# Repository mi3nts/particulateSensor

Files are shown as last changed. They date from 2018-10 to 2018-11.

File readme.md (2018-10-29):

# IoT Particulate Sensors

## Introduction 
With the increase in particulate emissions over the years, there is a need to be aware of the implications of toxic airbourne particles. These can have negative health outcomes on the population. Currently, air quality sensors are spaced far and wide from eachother collecting data at large time frames. They can also be often expensive. This project seeks to solve these issues and presents a low cost sensor network using a novel network communication known as LoRaWAN, a set of arduinos, and a gateway linux based Raspberry Pi 3. Combined with the calibration technique using machine learning algorithms, this sensor network can effectively provide the public with an accurate representation of air quality.

## Specifications
Uses a set of 10 arduino based nodes and 1 gateway Raspberry Pi 3.

- [Seeeduino LoRaWAN with GPS](https://m.seeedstudio.com/productDetail/2781/)
- [Grove Dust Sensor](https://www.seeedstudio.com/Grove-Dust-Sensor-p-1050.html/) 
- [Grove Barometer Sensor](https://www.seeedstudio.com/depot/Grove-Barometer-Sensor-BMP280-p-2652.html/) : I2C protocol

- Raspberry Pi 3 Model B
- [RHF0M301 module](http://www.risinghf.com/#/product-details?product_id=6&lang=en/) : serves as the communication bridge for the Raspberry Pi 3.

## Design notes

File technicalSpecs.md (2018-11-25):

# Low cost air quality IoT
This report gives the details of the sensor network and technical requirements.

## Primary Device: [Seeeduino LoRaWAN with GPS](https://m.seeedstudio.com/productDetail/2781/)
- Raspberry Pi 3 Model B
- [RHF0M301 module](http://www.risinghf.com/#/product-details?product_id=6&lang=en/)

### Sensors
These sensors are attached to the device.

| Sensor name | Description | Interface |
|---|---|---|
| [Grove Dust Sensor](https://www.seeedstudio.com/Grove-Dust-Sensor-p-1050.html/)  | Measures low pulse occupancy time as a correlate to particular matter. | Digital pin |
| [Grove Barometer Sensor](https://www.seeedstudio.com/depot/Grove-Barometer-Sensor-BMP280-p-2652.html/) | Measures temperature (celcius) and atmospheric pressure. | I2C | 
| [Grove Multichannel Gas Sensor](https://www.seeedstudio.com/Grove-Multichannel-Gas-Sensor-p-2502.html/) | Measures carbon monoxide, nitrogen dioxide, ethanol, hydrogen, ammonia, methane, propane, and isobutane in ppm. | I2C |

### Physical Characteristics
#### Dimensions
Seeeduino device dimensions with add-ons: 65mm x 55mm x 45mm (L x W x H) <br/>
Gateway device dimensions: 85mm x 55mm x 30mm (L x W x H, without antenna)

Seeeduino device enclosure: 120mm x 120mm x 275mm (L x W x H)
- See "3DModel" folder for computerized model of the casing.

Gateway device enclosure: X

#### Weight
Seeeduino device weight with add-ons: 0.25 kilograms <br/>
Gateway device weight: 0.20 kilograms

Seeeduino device with enclosure: 0.60 kilograms  </br>
Gateway device with enclosure: X

#### Power Requirements

Average power consumption on standby: 1.1 watt <br/>
Average power consumtpion during transmission: 1.2 watt <br/>
Voltage usage: 4.91 volts <br/>
Current usage: 0.20 amps

- [3.7 V Lithium Ion Battery](https://www.amazon.com/Battery-Lithium-2000mAh-Compatible-Controller/dp/B0137ITW46)
- [3W SEEED Solar Panel](https://cpc.farnell.com/seeed-studio/313070001/solar-panel-138x160-3w/dp/MK00376)

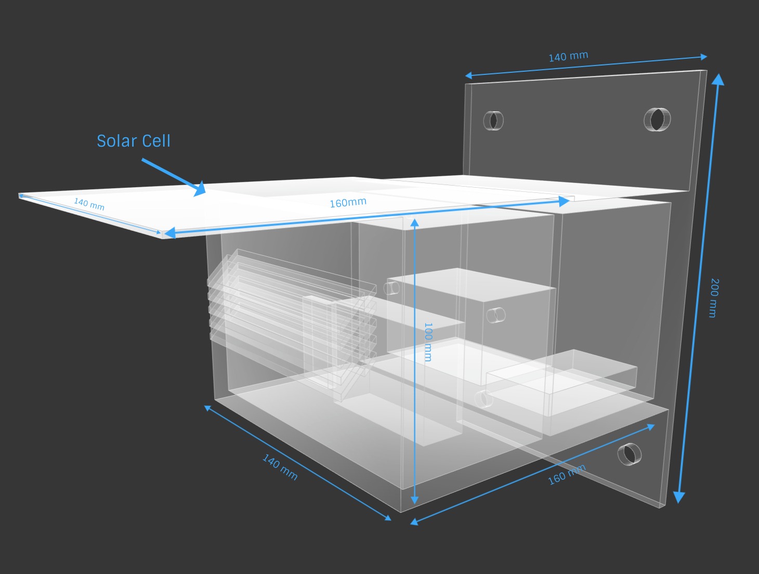
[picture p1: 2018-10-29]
3DModel/ParticulateSensor3.jpg

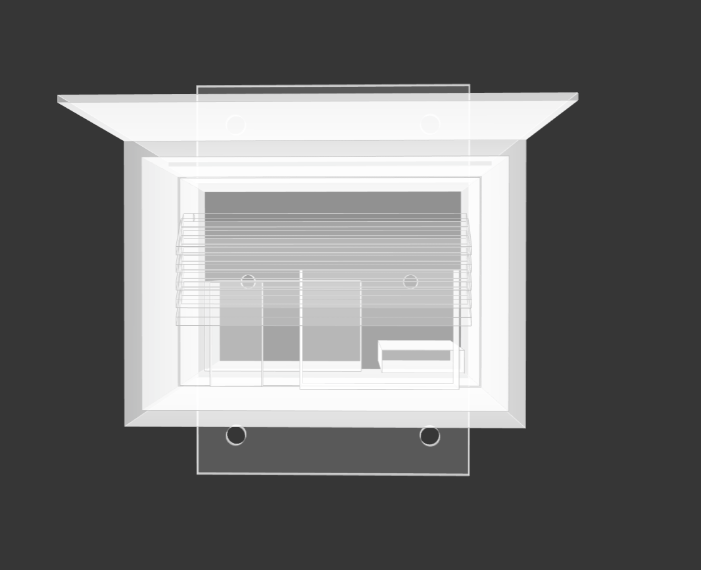
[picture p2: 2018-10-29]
3DModel/ParticulateSensor6.png

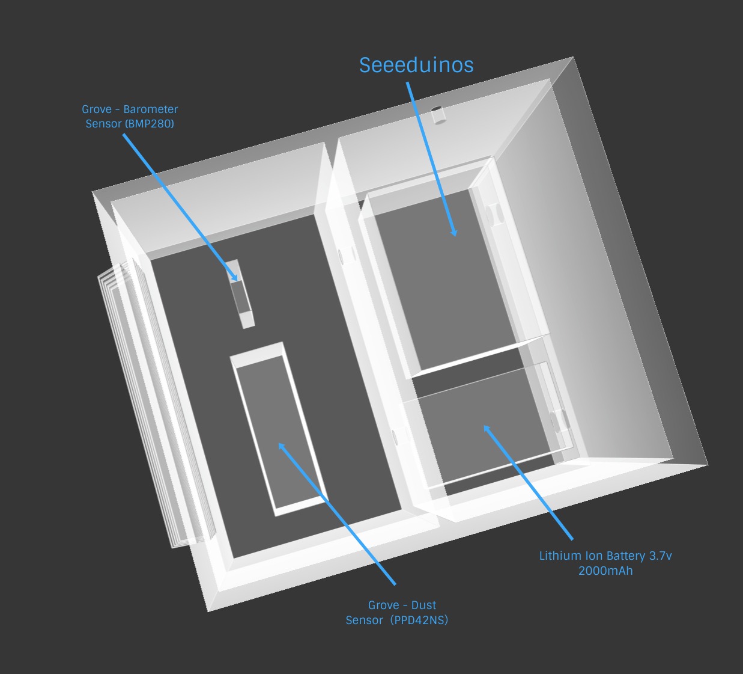
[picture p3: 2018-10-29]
3DModel/ParticulateSensor2.jpg

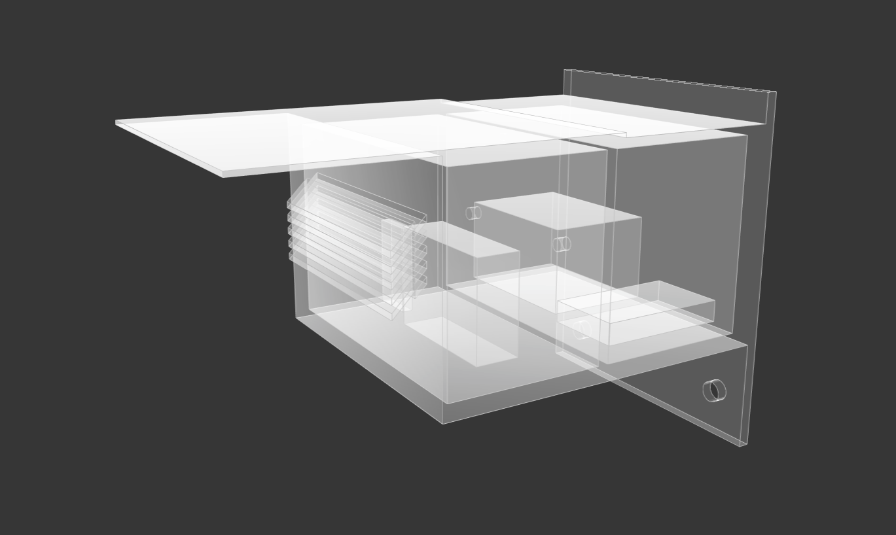
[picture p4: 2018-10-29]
3DModel/ParticulateSensor1.png

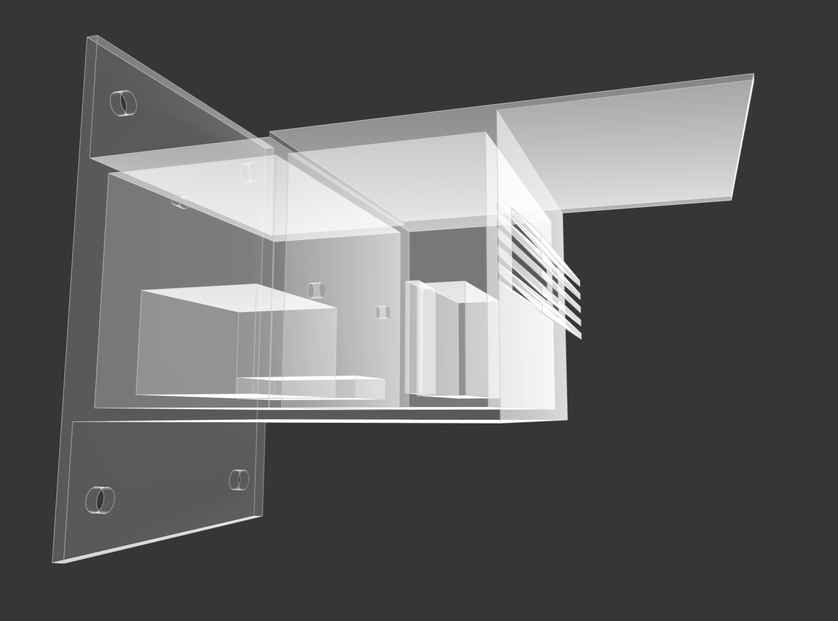
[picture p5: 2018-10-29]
3DModel/ParticulateSensor4.png

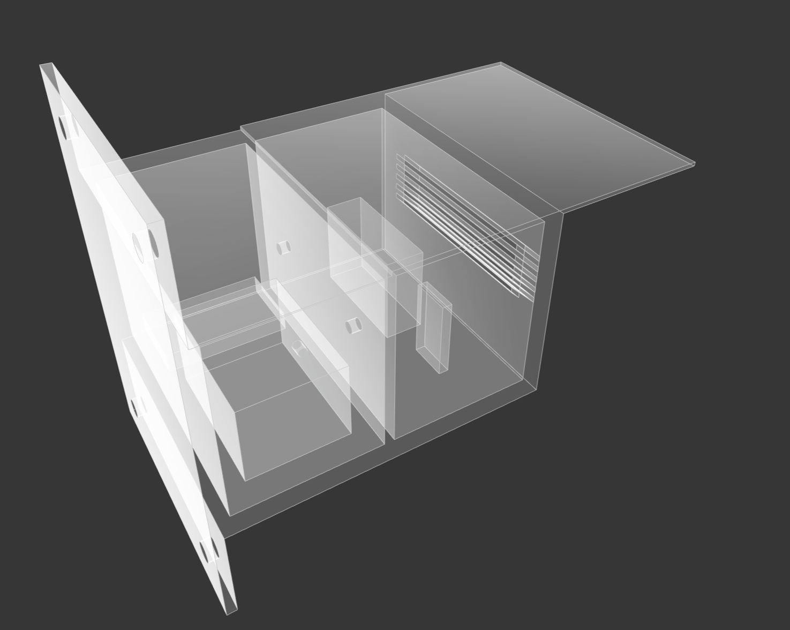
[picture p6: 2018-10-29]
3DModel/ParticulateSensor5.png

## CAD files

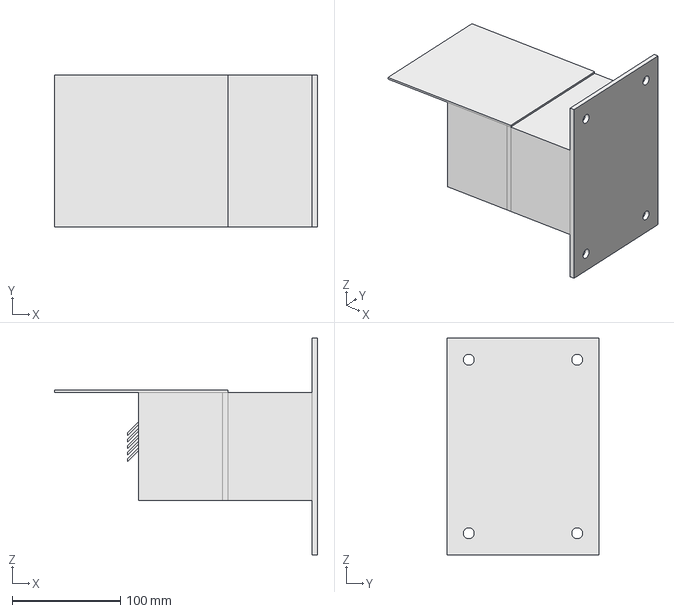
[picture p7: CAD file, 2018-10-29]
3DModel/ParticulateSensor.fcstd
242.5 x 140.0 x 200.0 mm

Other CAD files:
3DModel/ParticulateSensor.stl

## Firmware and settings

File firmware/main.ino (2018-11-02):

/*
 * MINTS
 * Written by Daniel Kiv
 * Version 0.1
 */

#include <math.h>
#include <stdio.h>
#include "Seeed_BMP280.h"
#include <Wire.h>
#include <LoRaWan.h>
#include "TinyGPS++.h"
#include <avr/dtostrf.h>
//#include "MutichannelGasSensor.h"

// gas sensors intializations
int pin = 8;
unsigned long duration;
unsigned long starttime;
unsigned long sampletime_ms = 1000;//sampe 30s ;
unsigned long lowpulseoccupancy = 0;
float ratio = 0;
float concentration = 0;

// bmp280 initializations
float pressure;
BMP280 bmp280;

#define USE_GPS 1
#ifdef USE_GPS
#include "TinyGPS++.h"
TinyGPSPlus gps;
#endif

const int analogInPin = A0;  // Analog input pin that the VBAT pin is attached to
int BatteryValue = 0;        // value read from the VBAT pin
float outputValue = 0;        // variable for voltage calculation

void setup() {

  char buffer[256];

  delay(1000);
  SerialUSB.println("Starting...");
  delay(1000);

   char c;
#ifdef USE_GPS
   bool locked;
#endif

  Serial.begin(9600);  // for gps readings
  Serial1.begin(9600);
  SerialUSB.begin(115200);
  lora.init();
  lora.setDeviceReset();

  #ifdef USE_GPS
    Serial.begin(9600);     // open the GPS
    locked = false;

    // For S&G, let's get the GPS fix now, before we start running arbitary
    // delays for the LoRa section

    while (!gps.location.isValid()) {
      while (Serial.available() > 0) {
        if (gps.encode(c=Serial.read())) {
//          displayInfo();
          if (gps.location.isValid()) {
//            locked = true;
            break;
          }
        }
//        SerialUSB.print(c);
      }

//      if (locked)
//        break;

      if (millis() > 15000 && gps.charsProcessed() < 10)
      {
        SerialUSB.println(F("No GPS detected: check wiring."));
        SerialUSB.println(gps.charsProcessed());
        while(true);
      }
      else if (millis() > 20000) {
        SerialUSB.println(F("Not able to get a fix in alloted time."));
        break;
      }
    }
#endif

  pinMode(pin,INPUT);
  if(!bmp280.init()) {
    SerialUSB.println("Device error!");
  }
  starttime = millis();//get the current time;

  // LoRaWan initializations
  memset(buffer, 0, 256);
  lora.getVersion(buffer, 256, 1);
  SerialUSB.print(buffer);

  memset(buffer, 0, 256);
  lora.getId(buffer, 256, 1);
  SerialUSB.print(buffer);

  lora.setKey("2B7E151628AED2A6ABF7158809CF4F3C", "2B7E151628AED2A6ABF7158809CF4F3C", NULL);

  lora.setDeciveMode(LWABP);
  lora.setDataRate(DR0, US915HYBRID);
//    sendCommand("AT+DR=US915HYBRID\r\n");

  lora.setChannel(0, 902.3);
  lora.setChannel(1, 902.5);
  lora.setChannel(2, 902.7);

//    lora.setChannel(0, 902.3, DR0, DR3);
//    lora.setChannel(1, 902.5, DR0, DR3);
//    lora.setChannel(2, 902.7, DR0, DR3);
//    lora.setChannel(3, 902.9, DR0, DR3);
//    lora.setChannel(4, 903.1, DR0, DR3);
//    lora.setChannel(5, 903.3, DR0, DR3);
//    lora.setChannel(6, 903.5, DR0, DR3);
//    lora.setChannel(7, 903.7, DR0, DR3);

//    lora.setReceiceWindowFirst(false);
//    lora.setReceiceWindowFirst(0, 923.3);
//    lora.setReceiceWindowFirst(1, 923.9);
//    lora.setReceiceWindowFirst(2, 924.5);
//    lora.setReceiceWindowFirst(3, 925.1);
//    lora.setReceiceWindowFirst(4, 925.7);
//    lora.setReceiceWindowFirst(5, 926.3);
//    lora.setReceiceWindowFirst(6, 926.9);
//    lora.setReceiceWindowFirst(7, 927.5);

  lora.setReceiceWindowFirst(0, 902.3);
  lora.setReceiceWindowSecond(923.3, DR8);

  lora.setDutyCycle(false);
  lora.setJoinDutyCycle(false);

  lora.setPower(14);

  SerialUSB.println("System booted!");

}

void loop() {
  bool result = false;
  char cat[15];
  char com[2] = ",";
  char payload[128] = "";

  dtostrf(bmp280.getTemperature(), 0, 2, cat);
  strcat(payload,cat);
  strcat(payload,com);
  dtostrf(bmp280.getPressure(), 0, 2, cat);
  strcat(payload,cat);
  strcat(payload,com);
  dtostrf(bmp280.calcAltitude(bmp280.getPressure()), 0, 2, cat);
  strcat(payload,cat);
  strcat(payload,com);

//    // read the analog in value:
//  BatteryValue = analogRead(analogInPin);
//  // Calculate the battery voltage value
//  outputValue = (float(BatteryValue)*5)/1023*2 - 2.75;
//  // print the results to the SerialUSB monitor:
//  SerialUSB.print("Analog value = " );
//  SerialUSB.print(BatteryValue);
//  SerialUSB.println(outputValue);
//  strcat(payload,cat);
//  strcat(payload,com);
//  dtostrf(gps.altitude.meters(), 0, 6, cat);

  duration = pulseIn(pin, LOW);
  lowpulseoccupancy = lowpulseoccupancy+duration;
  // SerialUSB.print("test");
  if ((millis()-starttime) > sampletime_ms)
  {
      ratio = lowpulseoccupancy/(sampletime_ms*10.0);  // Integer percentage 0=>100
      concentration = 1.1*pow(ratio,3)-3.8*pow(ratio,2)+520*ratio+0.62; // using spec sheet curve
      dtostrf(lowpulseoccupancy, 0, 0, cat);
      strcat(payload,cat);
      strcat(payload,com);
      dtostrf(ratio, 0, 2, cat);
      strcat(payload,cat);
      strcat(payload,com);
      dtostrf(concentration, 0, 2, cat);
      strcat(payload,cat);
      strcat(payload,com);
      lowpulseoccupancy = 0;
      starttime = millis();
  }

  if (gps.location.isValid())
  {
    dtostrf(gps.location.lat(), 0, 6, cat);
    strcat(payload,cat);
    strcat(payload,com);
    dtostrf(gps.location.lng(), 0, 6, cat);
    strcat(payload,cat);
    strcat(payload,com);
    dtostrf(gps.altitude.meters(), 0, 6, cat);
    strcat(payload,cat);
//    strcat(payload,"\r\n");
  }
  else
  {
    strcat(payload,"INVALIDGPSDATA");
//    strcat(payload,com);
  }

// send payloads
  SerialUSB.println(payload);
//  sendCommand(payload);
  result = lora.transferPacket(payload);

  delay(500);

//    memset(payload, '\0', 200);
}

void barometer() {

  //sprintf (intStr, "%d", int1);
  //get and print temperatures
  SerialUSB.print("Temp: ");
  SerialUSB.print(bmp280.getTemperature());
  SerialUSB.println("C");

  // ---------------- WORK -------------

  //sendATcommand("AT+CMSG=Pressure,","Done",2000);

  //get and print atmospheric pressure data
  SerialUSB.print("Pressure: ");
  pressure = bmp280.getPressure();
  SerialUSB.print(pressure);
  SerialUSB.println("Pa");

  //get and print altitude data
  SerialUSB.print("Altitude: ");
  SerialUSB.print(bmp280.calcAltitude(pressure));
  SerialUSB.println("m");

  SerialUSB.println("\n");//add a line between output of different times.

  //delay(1000);
}

void dustSensor() {
  duration = pulseIn(pin, LOW);
    lowpulseoccupancy = lowpulseoccupancy+duration;
    // SerialUSB.print("test");
    if ((millis()-starttime) > sampletime_ms)
    {
        ratio = lowpulseoccupancy/(sampletime_ms*10.0);  // Integer percentage 0=>100
        concentration = 1.1*pow(ratio,3)-3.8*pow(ratio,2)+520*ratio+0.62; // using spec sheet curve
        SerialUSB.print(lowpulseoccupancy);
        SerialUSB.print(",");
        SerialUSB.print(ratio);
        SerialUSB.print(",");
        SerialUSB.println(concentration);
        lowpulseoccupancy = 0;
        starttime = millis();
    }
}
